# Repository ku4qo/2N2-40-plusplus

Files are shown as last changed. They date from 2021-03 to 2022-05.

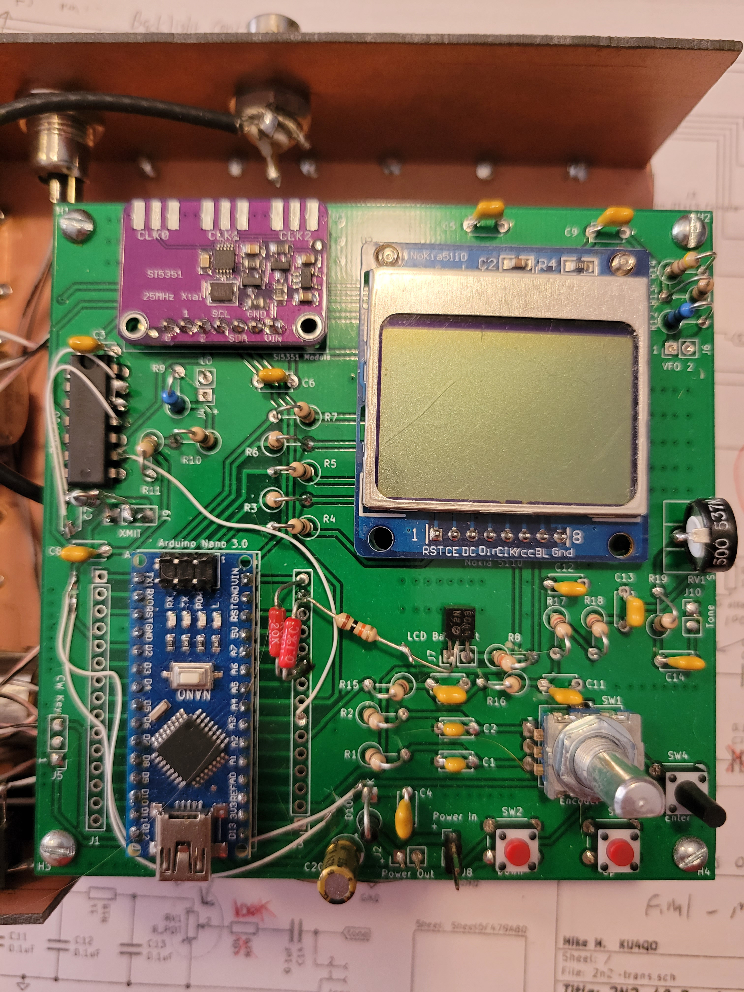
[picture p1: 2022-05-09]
digital board mods.jpg

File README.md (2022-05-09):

# 2N2-40-plusplus
This is very much an "alpha" level project. Proceed only if you want to get your hands dirty :)
Arduino software for the KU4QO version of K8IQY's 2n2-40 transceiver 
This is a work-in-progress. 
*VFO Program to run 2N2-40++ digital Transceiver - Press and hold enter on power up to start calibration
*swap pins XMIT_PWR and ENTER_BTN (D2 and D13) on digital board!
*si5351 clock 0 is vfo frequency, clock 1 is bfo frequency, clock 2 is transmit frequency; clock 0 is 
*temporarily used for calibrating the 25 MHz si5351 clock during the clock calibration routine.
*This version uses a Nokia 5110 LCD display.  Calibration routines use the enter button to advance.
*
Additional construction notes follow for these "alpha" version boards. See files "digital board mods" for additional details.

Attached is a photo of the digital board. There are a bunch of changes needed, so I figured a picture would help to follow along as well. Also attached are schematics of the boards as they were manufactured, along with lots of chicken-scratch writing about mods and values that were changed. You can see that the analog board is pretty much correct as-is, apart from a missing cap and a few value changes.

If you look at the two boards you'll see that the signals that travel between them have connectors in the exact same place. 

BFO
LO
Tone
Xmit
Power out digital/power in analog

The idea was to just have push-pin type connectors so that you could make the "sandwich" and easily pull it apart for changes or repairs. That didn't work out well for me so I used twisted-pair wires to connect between them. I don't notice any adverse results doing it that way. I'm sure it would work great with high-quality connectors, but the garbage ebay connectors I used were extremely noisy.

For the analog board, you need to add a 0.1uF cap across R11. Just tack solder it across the resistor or the pads. 

The winding information for all the inductors and transformers is printed on the schematic. The spots that have hand-written lengths in inches is me noting how much wire was needed to wind the coil. I used #28 wire. 

Transformer T6 is a little tricky since it has three windings. The sense of the windings is important. If you mix them up you'll make a very nice oscillator :)  The numbers start with odd, then end with even. So the first winding is 1 turn, starting at pin 1 and ending at pin 2. The next winding is 4 turns and starts at pin 3, goes in the same direction as the first winding, and ends at pin 4. Winding 3 starts at pin 5, goes in the same direction as the other two windings, and ends at pin 6. The pins are labeled on the pcb for clarity. 

Ground the IF crystal cases with a short wire to the spots labeled J10 through J13.

The audio output transformer has a P printed on one side. That is the primary (driven by the 2n2222 transistors). The unprinted side is the secondary (drives the speaker). 

Put a ferrite bead on the collector of Q4 before you solder it (for stability). 

The digital board requires a bunch of mods to get right. Here are my notes:

The schematic symbol for U4 says 74HC00, but it is important to use a 74ACT00. 

Be careful, there seem to be two different types of displays that have the Nokia display mounted on them. You can see the pins labeled in the photo attached. Make sure you buy and use a display that has the identical pinout. If you get one with the wrong pinout, it won't work as-is. 

On the 2 pin connector called "backlight", if you connect those pins the Nokia display backlight will turn on. Disconnect and it turns off. I was going to add computer control for this but ran out of output pins on the Arduino. So, on my board you'll see a transistor mounted in that spot. Ignore that and just add a jumper or a switch, or if you want the backlight on all the time, just short those two pins.

Add two resistors, 10k and 20k, as feedback to the Arduino for the supply voltage display. These don't have a position, so just solder them to the top of the board. You'll see that I used two red-colored resistors here. They are 0.1% resistors, but using regular 1% resistors is fine. If you don't have a 20k, use two 10k in series. 

There are two control lines that need to be swapped, which requires cutting traces and running mod wires. The Arudino nano has an LED that is attached to D13. If you use D13 as an input you have to remove that LED or the input doesn't work. Instead, I swapped what was connected to D2 with D13. You can see the two white mod wires that wrap around the bottom left corner of the arduino. The ends of those wires attach to the two trace cuts. One cut is by D100, and the other is by C8. 

You need to add a 10k resistor to ground from the XMIT_PWR line, which is now connect to Arudino pin D13 (after the mod above). This keeps the power off off of the finals during restart.

Before you install U4 (74ACT00), bend up pins 11, 12 and 13. Also, before you install it, cut the trace between pins 9 and 10. Do not load C7. Instead, use those pads as connection points for the mod wires. We're turning gate U4C from an inverter into a NAND gate, and using the spare U4D as an inverter. Pin 9 is then connected to Arduino pin A3. This allows us to gate the transmitter clock properly to keep the finals turned off during receive. 

For R19, use 100k instead of 10k. Use the 500 pot I sent as RV1. You'll have to be a little creative to solder in the pot since it doesn't match the pads. I bent the pins and used it vertically, and added a wire to the wiper connection down to the board. Also keep in mind that the pot is backwards, so fully clockwise is the lowest sidetone level, and it increases as you turn CCW. You won't need much since the audio amp is so sensitive, so start fully CW, then tweak carefully until you get the sidetone level you want. 

Both U4A and U4B drive attenuators before the signals go down to the mixers on the analog board. Use the resistor values in red for both of those attenuators. 

I'd suggest building the digital board first and getting it all working properly before you continue to the analog section. That way, you can check the outputs and make sure everything looks good before you build the analog board. You can test the display, swithces, Si5351 and keyer functions first before continuing. 

Just like all the other radios that use a class E amplifier for the finals (i.e. QCX), they are sensitive to being operated into an open or short circuit. When you first turn on the analog board, make sure you have a dummy load connected to the antenna, just in case something weird is happening and it tries to transmit. BS170 aren't expensive, but you don't want to smoke them if you can avoid it.

Notice that +12V power is first applied to the digital board, then routed down to the analog board. Each board has a schottky diode to protect it from reverse polarity. The two boards together draw about 140mA from my benchtop supply with no input signal. Yours should be close to that. If not, something is probably wrong.

Mine puts out a bit over 4 watts at 12VDC, and the amplifier is amazingly efficient. The entire radio only draws around 500mA when transmitting. 

Ok, I think that covers it. Take a look at the schematic and let me know if there are any parts that you don't have. If I have them I'll toss them in the box before I ship it on monday.

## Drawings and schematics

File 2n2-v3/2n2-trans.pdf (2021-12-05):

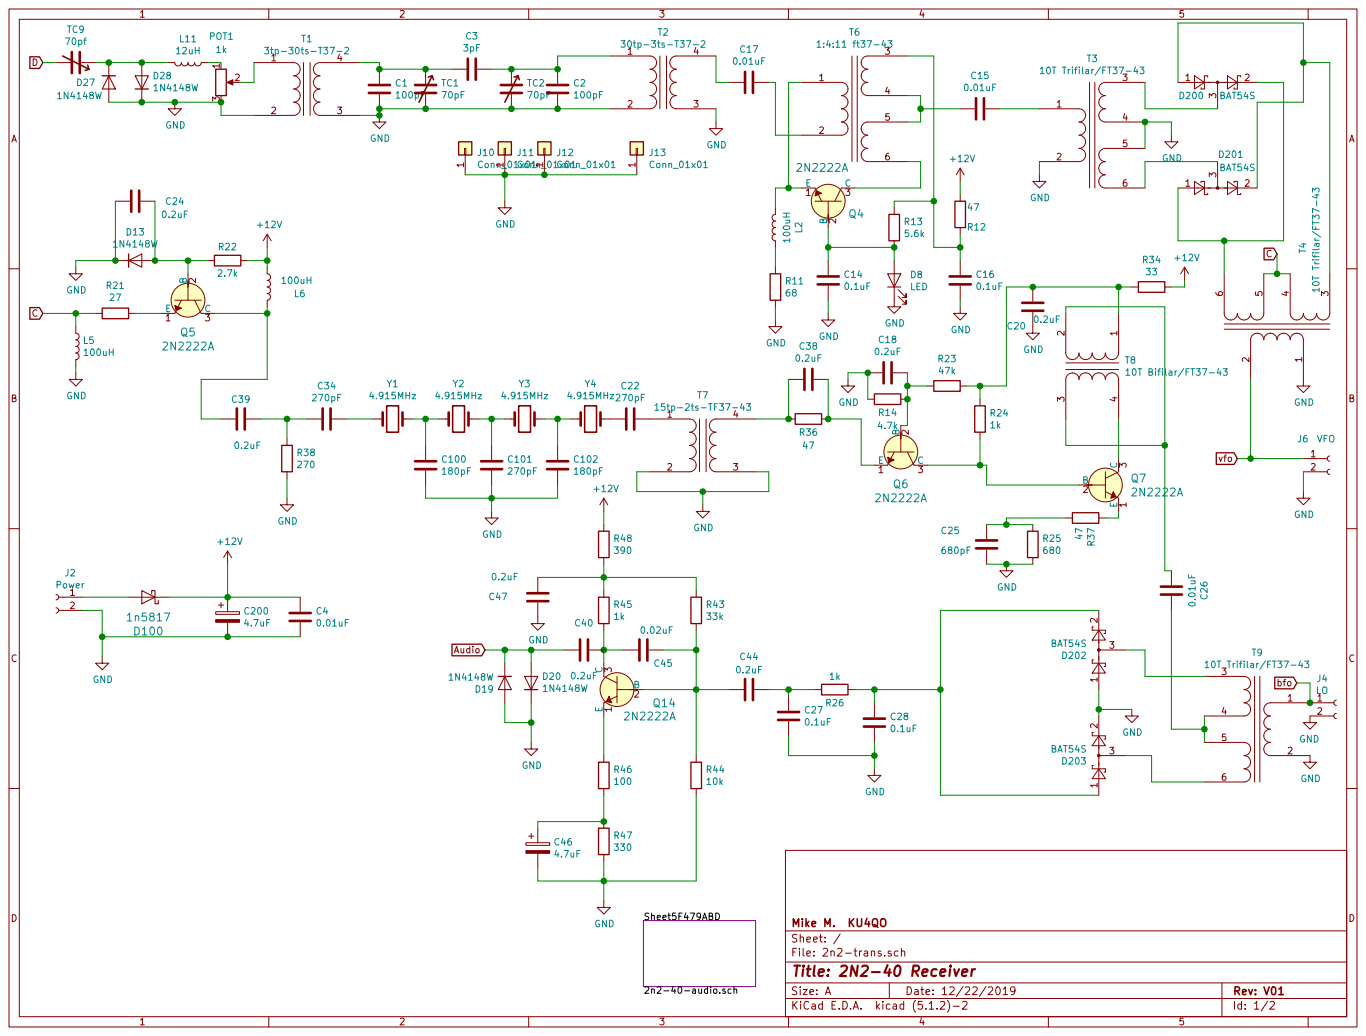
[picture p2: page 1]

Id: 1/2 Title: 2N2-40 Receiver File: 2n2-trans.sch Sheet: / Mike M. KU4QO

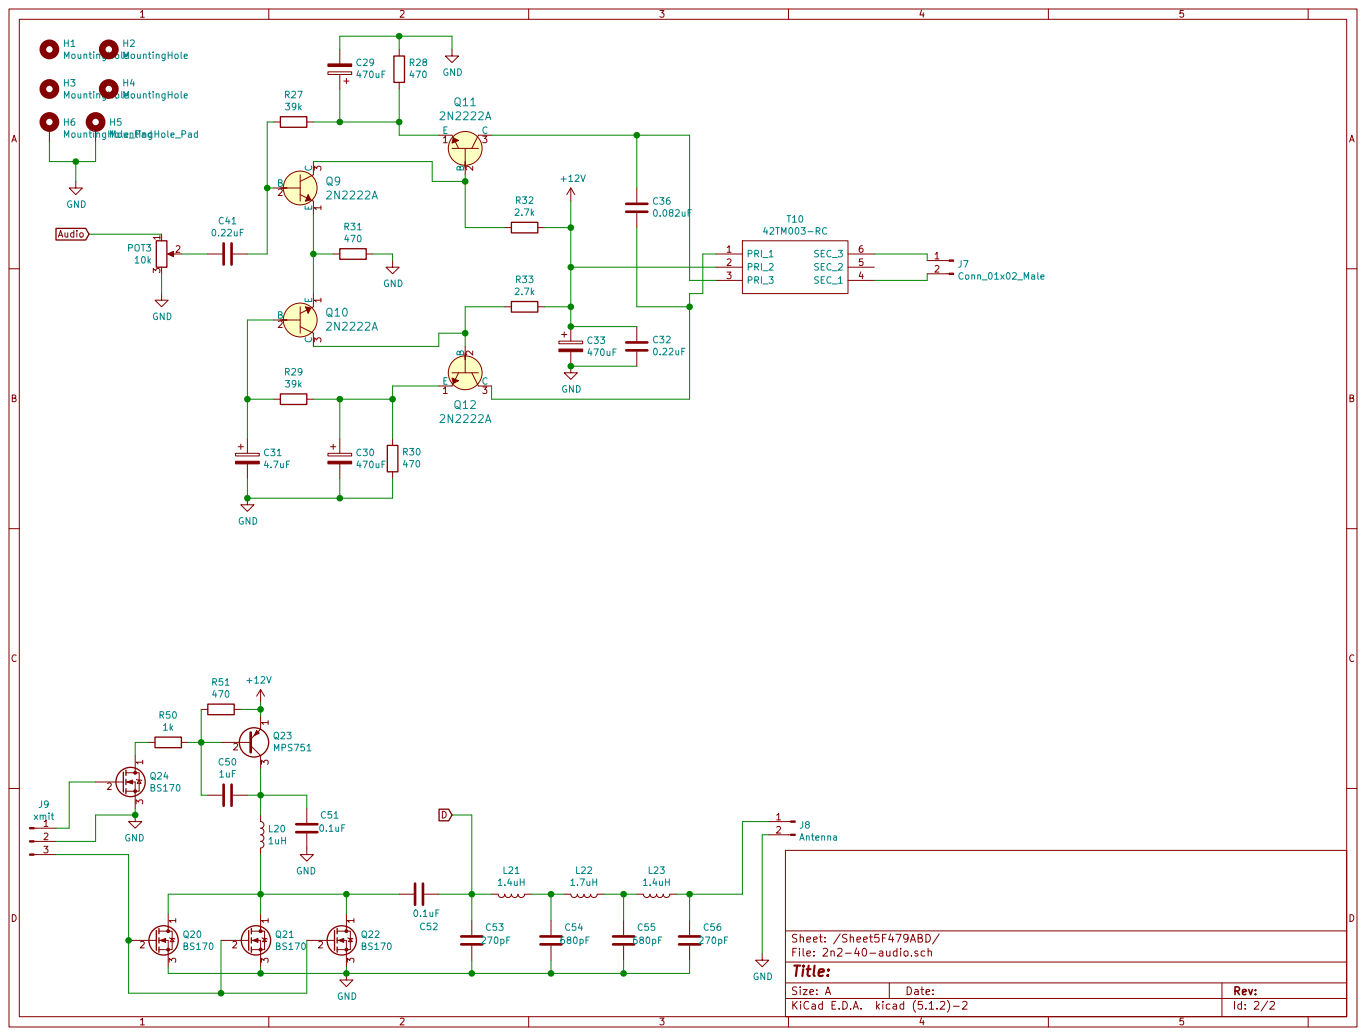
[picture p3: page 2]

Id: 2/2 Title: File: 2n2-40-audio.sch Sheet: /Sheet5F479ABD/

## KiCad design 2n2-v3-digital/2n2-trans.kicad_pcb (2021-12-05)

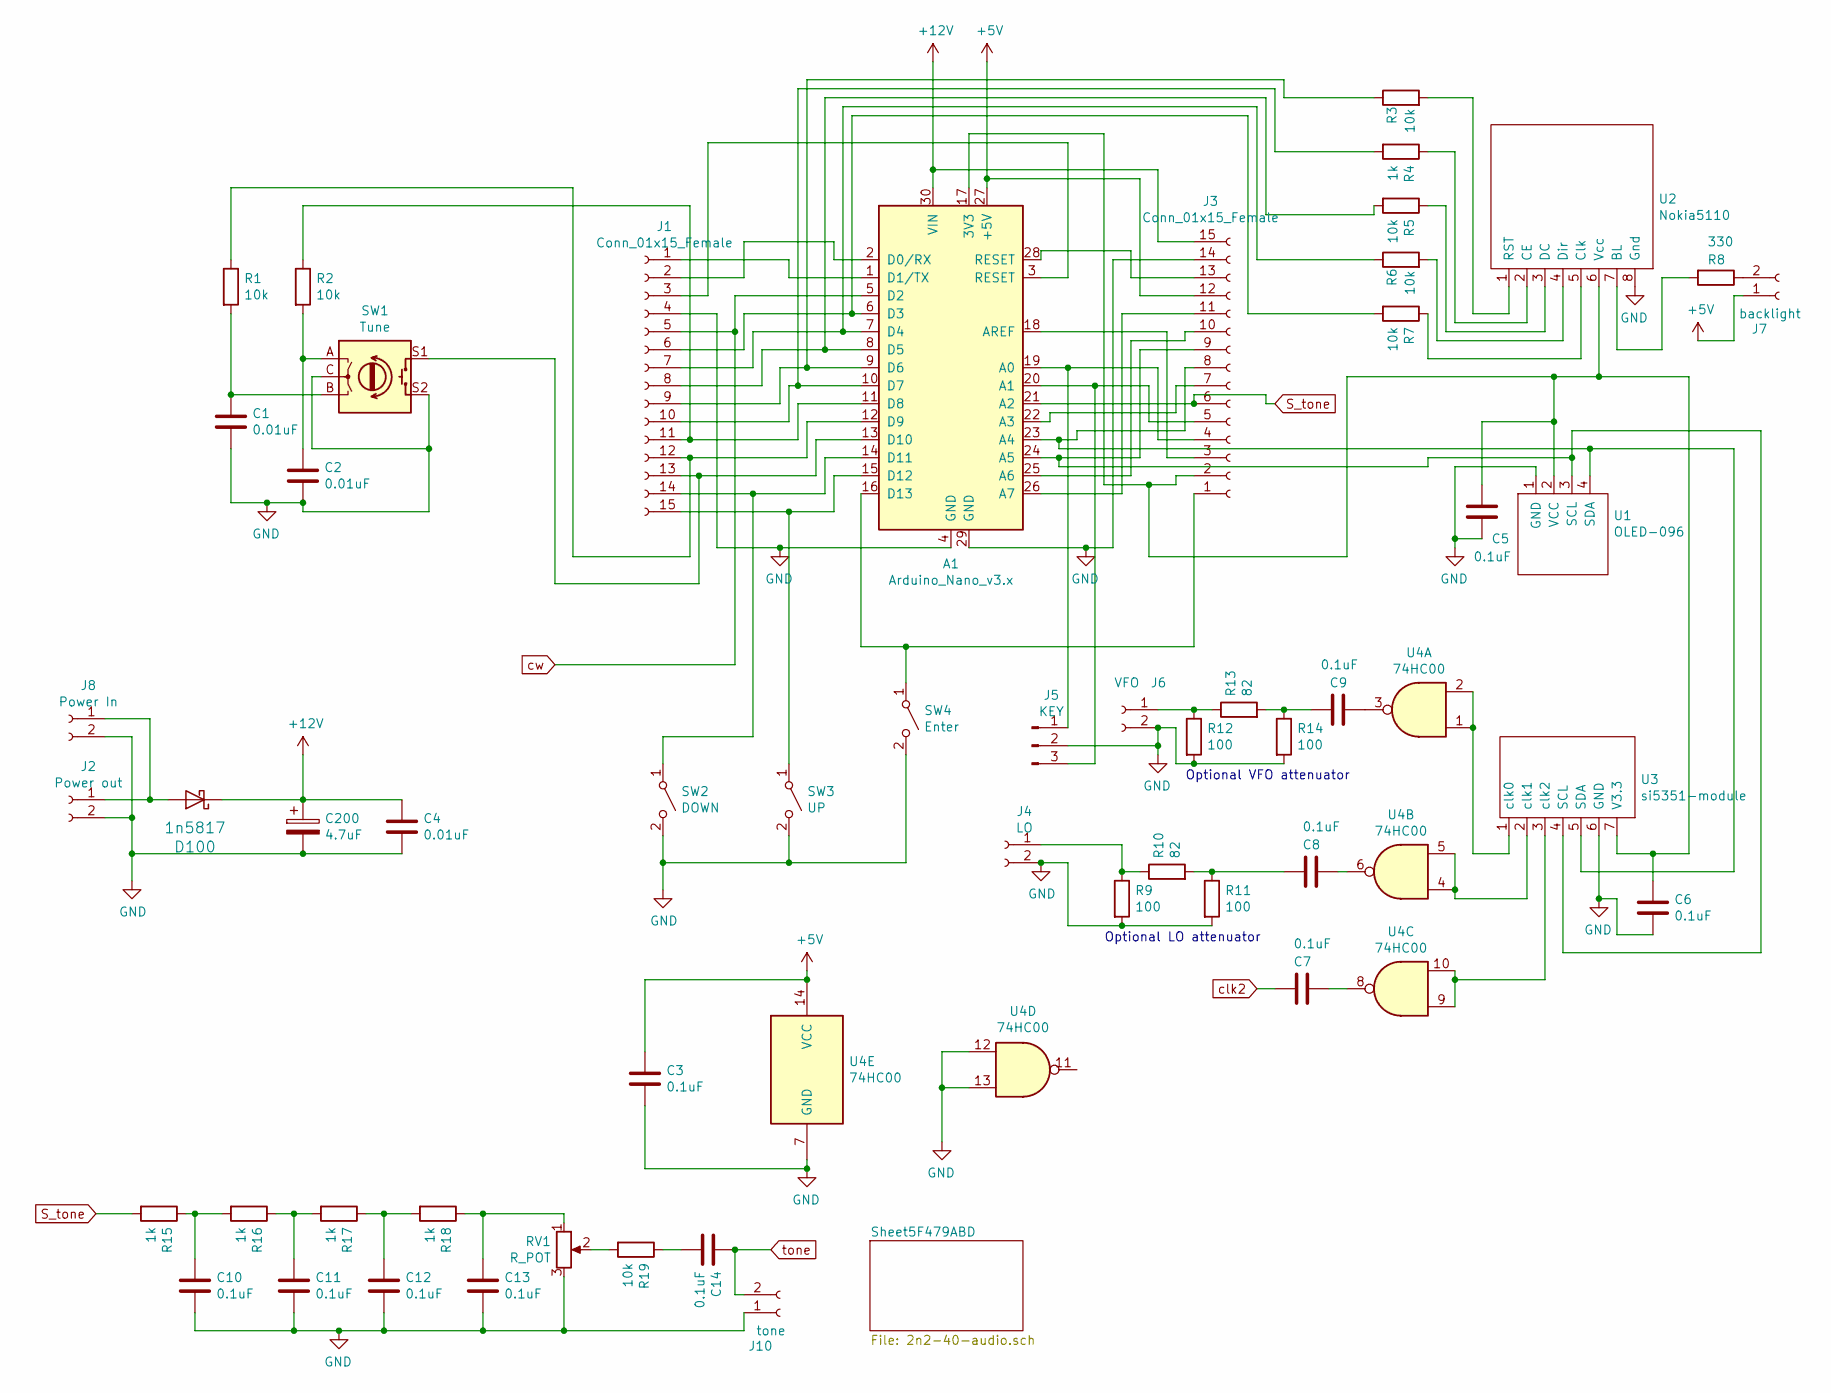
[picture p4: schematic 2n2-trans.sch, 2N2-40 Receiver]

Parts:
A1: Arduino_Nano_v3.x; Arduino_Nano
C1, C2, C4: 0.01uF; C_Disc_D4.7mm_W2.5mm_P5.00mm
C3, C5, C6, C7, C8, C9, C10, C11, C12, C13, C14: 0.1uF; C_Disc_D4.7mm_W2.5mm_P5.00mm
C200: 4.7uF; CP_Radial_D5.0mm_P2.00mm
D100: 1n5817; D_DO-41_SOD81_P3.81mm_Vertical_KathodeUp
J1, J3: Conn_01x15_Female; PinHeader_1x15_P2.54mm_Vertical
J2: Power out; PinHeader_1x02_P2.54mm_Vertical
J4: LO; PinHeader_1x02_P2.54mm_Vertical
J5: KEY; PinHeader_1x03_P2.54mm_Vertical
J6: VFO; PinHeader_1x02_P2.54mm_Vertical
J7: backlight; PinHeader_1x02_P2.54mm_Vertical
J8: Power In; PinHeader_1x02_P2.54mm_Vertical
J10: tone; PinHeader_1x02_P2.54mm_Vertical
R1, R2, R3, R5, R6, R7, R19: 10k; R_Axial_DIN0309_L9.0mm_D3.2mm_P5.08mm_Vertical
R4, R15, R16, R17, R18: 1k; R_Axial_DIN0309_L9.0mm_D3.2mm_P5.08mm_Vertical
R8: 330; R_Axial_DIN0309_L9.0mm_D3.2mm_P5.08mm_Vertical
R9, R11, R12, R14: 100; R_Axial_DIN0309_L9.0mm_D3.2mm_P5.08mm_Vertical
R10, R13: 82; R_Axial_DIN0309_L9.0mm_D3.2mm_P5.08mm_Vertical
RV1: R_POT; Potentiometer_Piher_PT-10-H01_Horizontal
SW1: Tune; RotaryEncoder_Alps_EC11E-Switch_Vertical_H20mm
SW2: DOWN; SW_PUSH_6mm_H5mm
SW3: UP; SW_PUSH_6mm_H5mm
SW4: Enter; SW_PUSH_6mm_H5mm
U1: OLED-096; oled096
U2: Nokia5110
U3: si5351-module
U4: 74HC00

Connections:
+5V: A1.27 (+5V), C3.1, J3.12, J7.1, U4.14 (VCC)
+12V: A1.30 (VIN), C4.1, C200.1, D100.1 (K), J3.15
GND: A1.4 (GND), A1.29 (GND), C1.2, C2.2, C3.2, C4.2, C5.2, C6.2, C10.2, C11.2, C12.2, C13.2, C200.2, J1.4, J2.2, J3.14, J4.2, J5.2, J6.2, J8.2, J10.1, R9.2, R11.2, R12.2, R14.2, RV1.3, SW1.C, SW1.S2, SW2.2 (B), SW3.2 (B), SW4.2 (B), U1.1 (GND), U2.8 (Gnd), U3.6 (GND), U4.7 (GND), U4.12, U4.13; also elsewhere on the board
unnamed: A1.1 (D1/TX), J1.1
unnamed: A1.2 (D0/RX), J1.2
unnamed: A1.3 (RESET), J1.3
unnamed: A1.6 (D3), J1.6, R7.2
unnamed: A1.7 (D4), J1.7, R6.1
unnamed: A1.8 (D5), J1.8, R5.2
unnamed: A1.9 (D6), J1.9, R3.1
unnamed: A1.10 (D7), J1.10, R4.2
unnamed: A1.11 (D8), J1.11, R2.1
unnamed: A1.12 (D9), J1.12, R1.1
unnamed: A1.13 (D10), J1.13, SW1.S1
unnamed: A1.14 (D11), J1.14, SW2.1 (A)
unnamed: A1.15 (D12), J1.15, SW3.1 (A)
unnamed: A1.16 (D13), J3.1, SW4.1 (A)
unnamed: A1.17 (3V3), C5.1, C6.1, J3.2, U1.2 (VCC), U2.6 (Vcc), U3.7 (V3.3)
unnamed: A1.18 (AREF), J3.3
unnamed: A1.19 (A0), J3.4, J5.1
unnamed: A1.20 (A1), J3.5, J5.3
unnamed: A1.22 (A3), J3.7
unnamed: A1.23 (A4), J3.8, U1.4 (SDA), U3.5 (SDA)
unnamed: A1.24 (A5), J3.9, U1.3 (SCL), U3.4 (SCL)
unnamed: A1.25 (A6), J3.10
unnamed: A1.26 (A7), J3.11
unnamed: A1.28 (RESET), J3.13
unnamed: C1.1, R1.2, SW1.B
unnamed: C2.1, R2.2, SW1.A
unnamed: C7.1, U4.8
unnamed: C8.1, U4.6
unnamed: C8.2, R10.2, R11.1
unnamed: C9.1, U4.3
unnamed: C9.2, R13.2, R14.1
unnamed: C10.1, R15.1, R16.2
unnamed: C11.1, R16.1, R17.2
unnamed: C12.1, R17.1, R18.2
unnamed: C13.1, R18.1, RV1.1
unnamed: C14.2, R19.1
unnamed: D100.2 (A), J2.1, J8.1
unnamed: J4.1, R9.1, R10.1
unnamed: J6.1, R12.1, R13.1
unnamed: J7.2, R8.1
unnamed: R3.2, U2.1 (RST)
unnamed: R4.1, U2.2 (CE)
unnamed: R5.1, U2.3 (DC)
unnamed: R6.2, U2.4 (Dir)
unnamed: R7.1, U2.5 (Clk)
unnamed: R8.2, U2.7 (BL)
unnamed: R19.2, RV1.2
unnamed: U3.1 (clk0), U4.1, U4.2
unnamed: U3.2 (clk1), U4.4, U4.5
unnamed: U3.3 (clk2), U4.9, U4.10
S_tone: A1.21 (A2), J3.6, R15.2
clk2: C7.2; also elsewhere on the board
cw: A1.5 (D2), J1.5; also elsewhere on the board
tone: C14.1, J10.2

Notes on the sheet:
Optional VFO attenuator
Optional LO attenuator

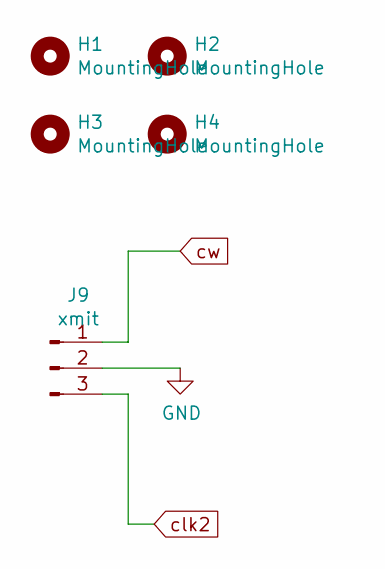
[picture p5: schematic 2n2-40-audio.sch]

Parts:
H1, H2, H3, H4: MountingHole; MountingHole_3.2mm_M3
J9: xmit; PinHeader_1x03_P2.54mm_Vertical

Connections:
GND: J9.2; also elsewhere on the board
clk2: J9.3; also elsewhere on the board
cw: J9.1; also elsewhere on the board

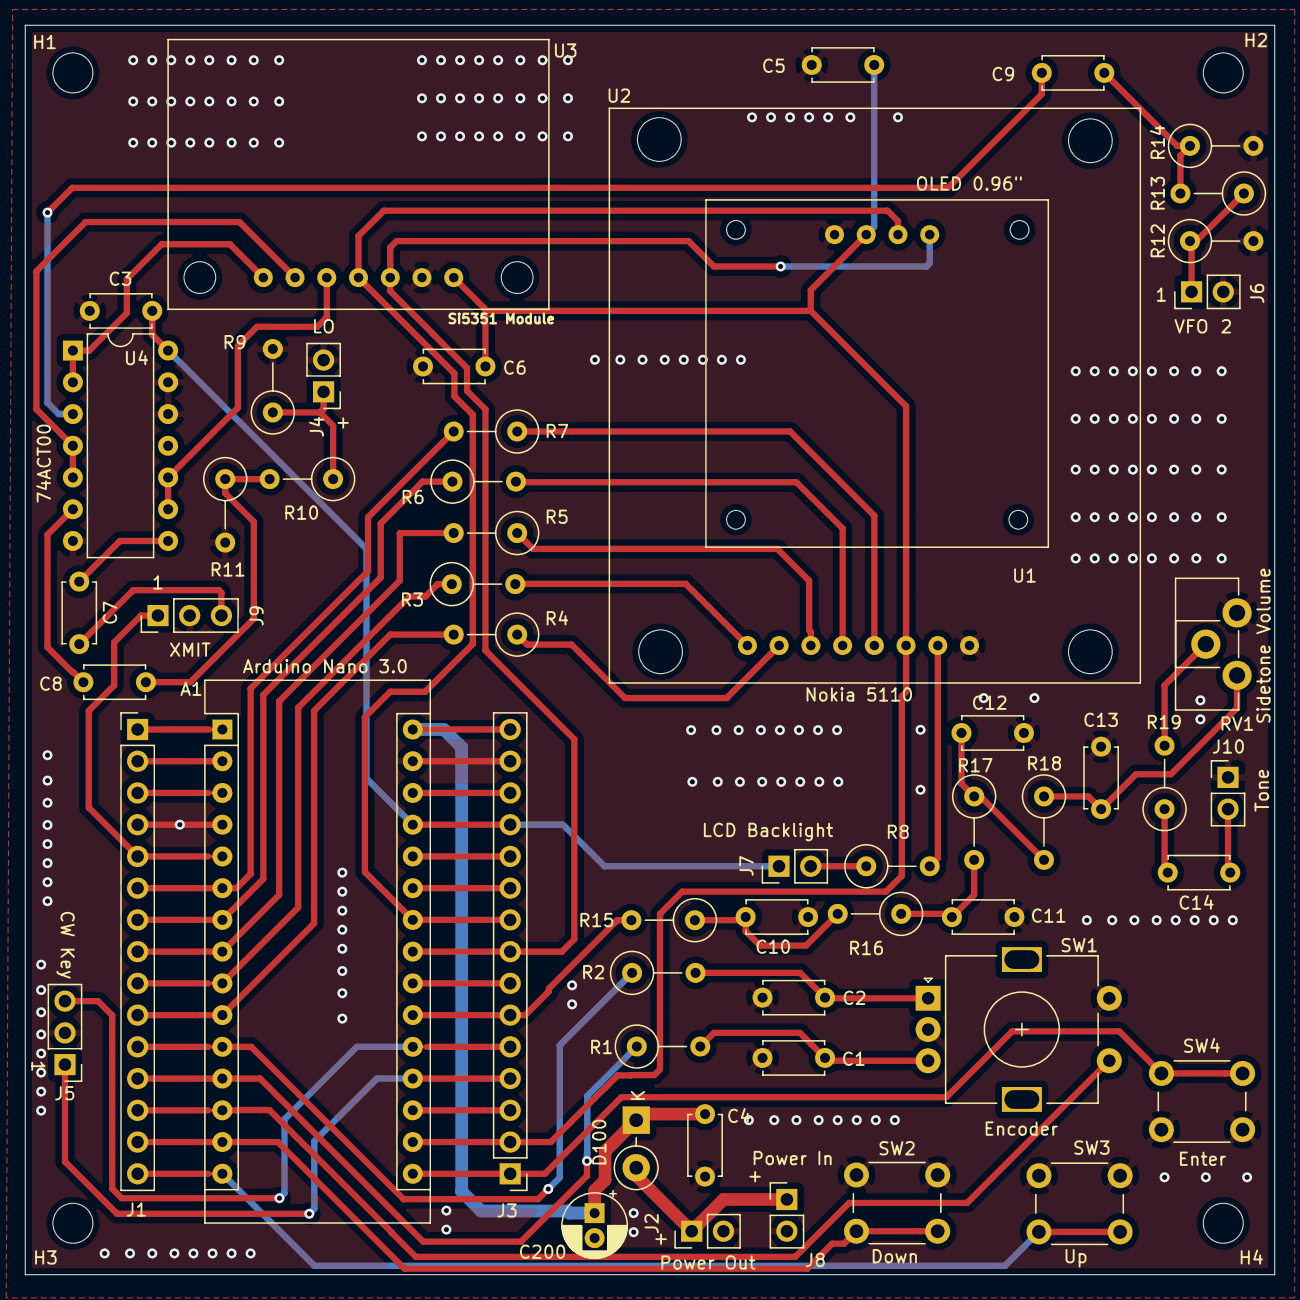
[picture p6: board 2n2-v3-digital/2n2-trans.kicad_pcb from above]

Board: 2 copper layers, 100.0 x 100.0 mm, 59 parts (0 on the bottom side), 57 nets.

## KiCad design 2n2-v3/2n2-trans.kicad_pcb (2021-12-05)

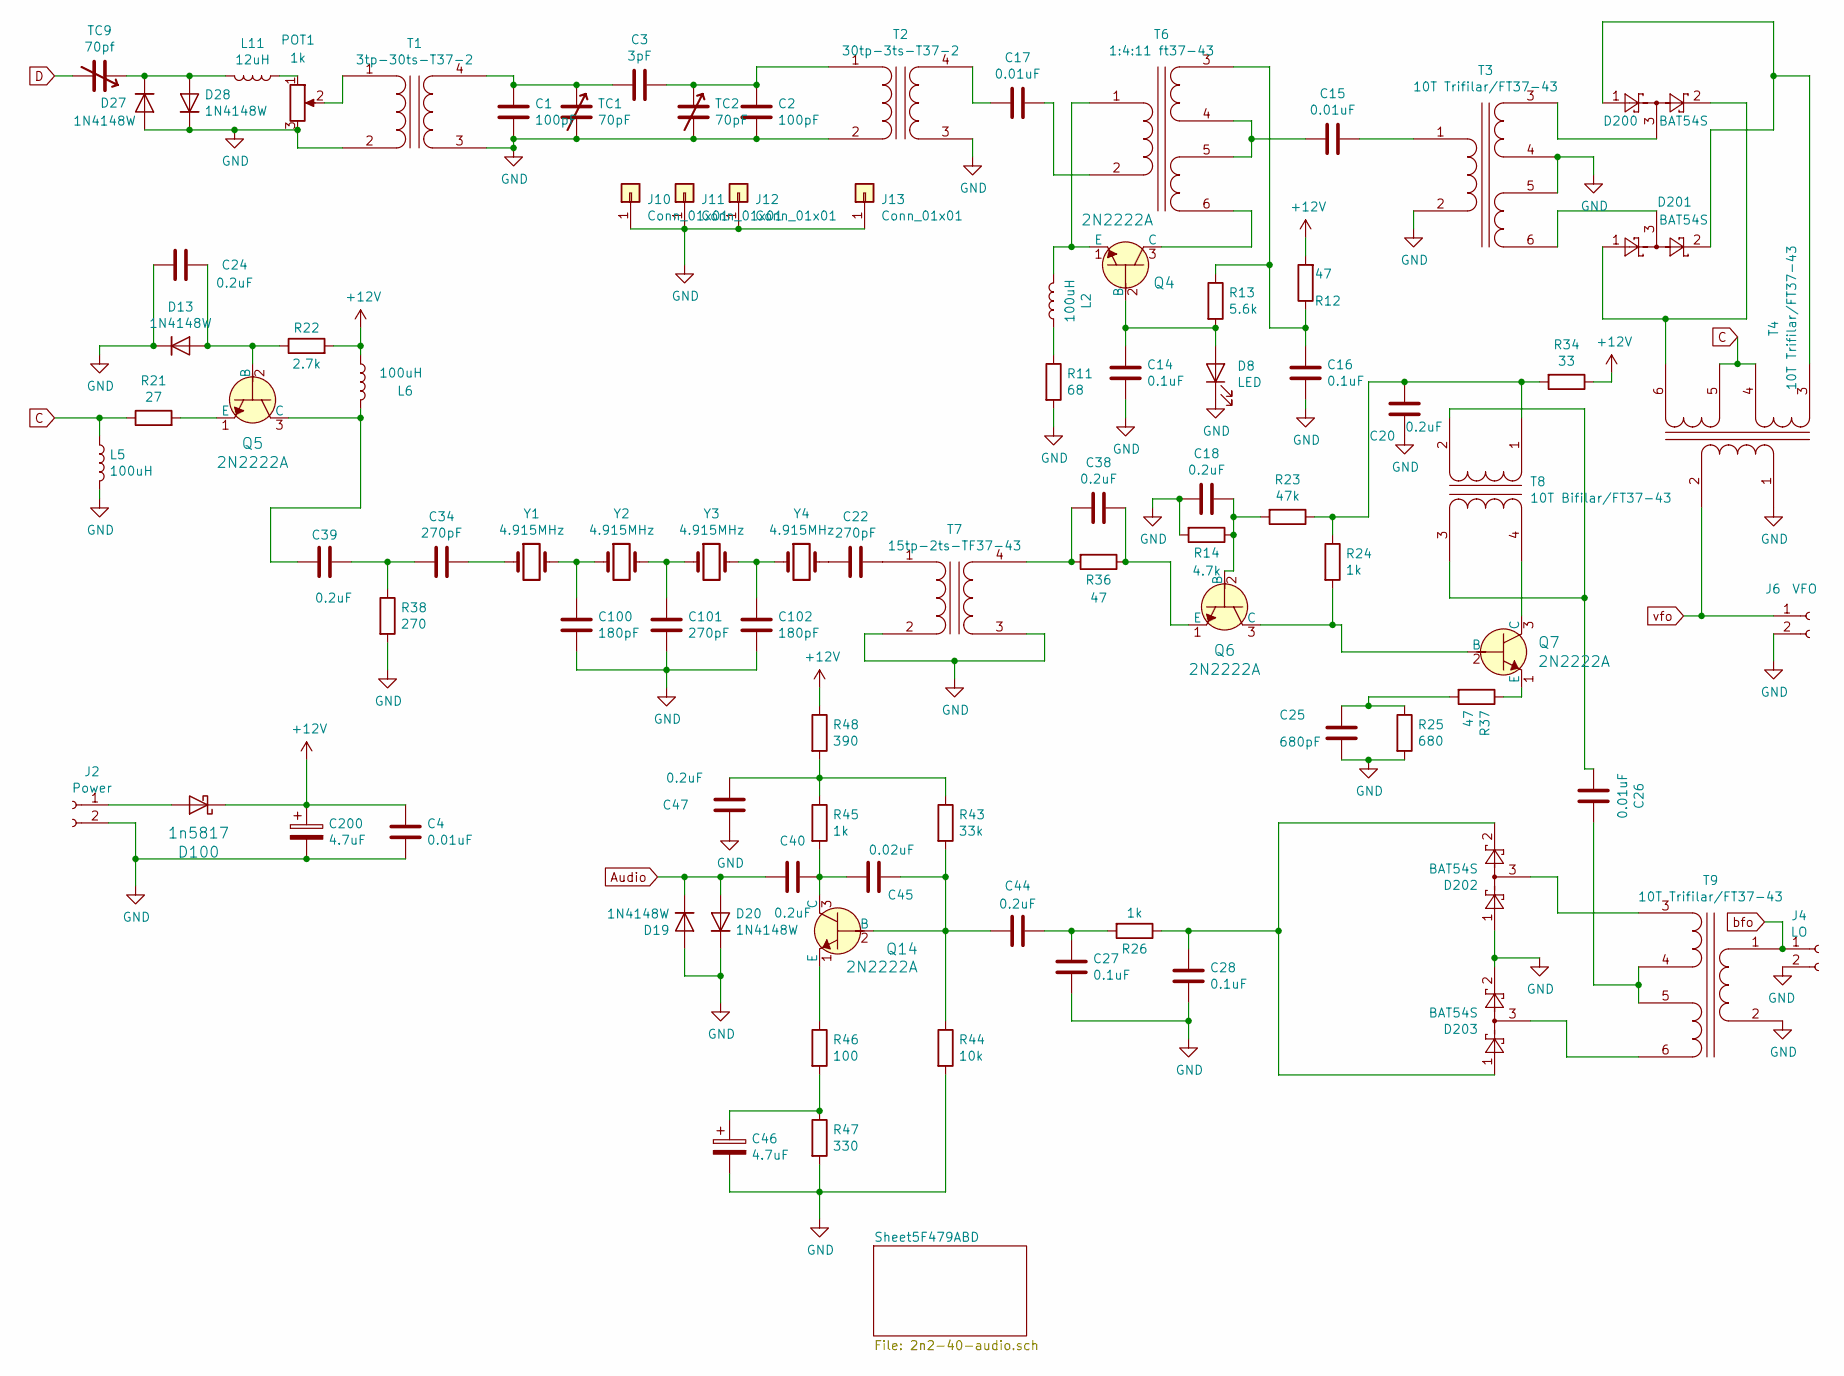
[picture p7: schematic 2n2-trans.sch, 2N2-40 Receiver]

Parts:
C1, C2: 100pF; C_Disc_D4.7mm_W2.5mm_P5.00mm
C3: 3pF; C_Disc_D4.7mm_W2.5mm_P5.00mm
C4: 0.01uF; C_Disc_D4.7mm_W2.5mm_P5.00mm
C14: 0.1uF; C_Disc_D4.7mm_W2.5mm_P5.00mm
C15, C17, C26: 0.01uF; C_Disc_D5.1mm_W3.2mm_P5.00mm
C16, C27, C28: 0.1uF; C_Disc_D5.1mm_W3.2mm_P5.00mm
C18, C20, C24, C38, C39, C40, C44, C47: 0.2uF; C_Disc_D5.1mm_W3.2mm_P5.00mm
C22, C34, C101: 270pF; C_Disc_D10.0mm_W2.5mm_P5.00mm
C25: 680pF; C_Disc_D5.1mm_W3.2mm_P5.00mm
C45: 0.02uF; C_Disc_D5.1mm_W3.2mm_P5.00mm
C46, C200: 4.7uF; CP_Radial_D5.0mm_P2.00mm
C100, C102: 180pF; C_Disc_D8.0mm_W2.5mm_P5.00mm
D8: LED; LED_D5.0mm
D13: 1N4148W; D_DO-35_SOD27_P2.54mm_Vertical_KathodeUp
D19, D20, D27, D28: 1N4148W; D_DO-41_SOD81_P3.81mm_Vertical_KathodeUp
D100: 1n5817; D_DO-41_SOD81_P3.81mm_Vertical_KathodeUp
D200, D201, D202, D203: BAT54S; SOT-23
J2: Power; PinHeader_1x02_P2.54mm_Vertical
J4: LO; PinHeader_1x02_P2.54mm_Vertical
J6: VFO; PinHeader_1x02_P2.54mm_Vertical
J10, J11, J12, J13: Conn_01x01; PinHeader_1x01_P1.27mm_Vertical
L2, L5, L6: 100uH; L_Axial_L7.0mm_D3.3mm_P5.08mm_Vertical_Fastron_MICC
L11: 12uH; L_Axial_L7.0mm_D3.3mm_P5.08mm_Vertical_Fastron_MICC
POT1: 1k; PinHeader_1x03_P2.54mm_Vertical
Q4, Q5, Q6, Q7, Q14: 2N2222A; TO-92_Inline; MPN 2N2222A; Digi-Key_PN 2N2222ACS-ND
R11: 68; R_Axial_DIN0309_L9.0mm_D3.2mm_P5.08mm_Vertical
R12, R36, R37: 47; R_Axial_DIN0309_L9.0mm_D3.2mm_P5.08mm_Vertical
R13: 5.6k; R_Axial_DIN0309_L9.0mm_D3.2mm_P5.08mm_Vertical
R14: 4.7k; R_Axial_DIN0309_L9.0mm_D3.2mm_P5.08mm_Vertical
R21: 27; R_Axial_DIN0309_L9.0mm_D3.2mm_P5.08mm_Vertical
R22: 2.7k; R_Axial_DIN0309_L9.0mm_D3.2mm_P5.08mm_Vertical
R23: 47k; R_Axial_DIN0309_L9.0mm_D3.2mm_P5.08mm_Vertical
R24, R26, R45: 1k; R_Axial_DIN0309_L9.0mm_D3.2mm_P5.08mm_Vertical
R25: 680; R_Axial_DIN0309_L9.0mm_D3.2mm_P5.08mm_Vertical
R34: 33; R_Axial_DIN0309_L9.0mm_D3.2mm_P5.08mm_Vertical
R38: 270; R_Axial_DIN0309_L9.0mm_D3.2mm_P5.08mm_Vertical
R43: 33k; R_Axial_DIN0309_L9.0mm_D3.2mm_P5.08mm_Vertical
R44: 10k; R_Axial_DIN0309_L9.0mm_D3.2mm_P5.08mm_Vertical
R46: 100; R_Axial_DIN0309_L9.0mm_D3.2mm_P5.08mm_Vertical
R47: 330; R_Axial_DIN0309_L9.0mm_D3.2mm_P5.08mm_Vertical
R48: 390; R_Axial_DIN0309_L9.0mm_D3.2mm_P5.08mm_Vertical
T1: 3tp-30ts-T37-2; ToroidTrans
T2: 30tp-3ts-T37-2; ToroidTrans
T3, T4, T9: 10T Trifilar/FT37-43; ToroidTri
T6: 1:4:11 ft37-43; ToroidTri
T7: 15tp-2ts-TF37-43; ToroidTrans
T8: 10T Bifilar/FT37-43; ToroidTrans
TC1, TC2: 70pF; tcap
TC9: 70pf; tcap
Y1, Y2, Y3, Y4: 4.915MHz; Crystal_HC49-U_Vertical

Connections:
+12V: C4.1, C200.1, D100.1 (K), L6.1, R12.2, R22.2, R34.1, R48.1; also elsewhere on the board
Audio: C40.1, D19.1 (K), D20.2 (A); also elsewhere on the board
C: L5.1, R21.1, T4.4 (SB), T4.5 (SC)
D: TC9.2; also elsewhere on the board
GND: C1.2, C2.2, C4.2, C14.2, C16.2, C18.2, C20.1, C24.2, C25.1, C27.2, C28.2, C46.2, C47.1, C100.2, C101.2, C102.2, C200.2, D8.1 (K), D13.1 (K), D19.2 (A), D20.1 (K), D27.2 (A), D28.1 (K), D202.1, D203.2, J2.2, J4.2, J6.2, J10.1, J11.1, J12.1, J13.1, L5.2, POT1.3, R11.2, R14.2, R25.2, R38.2, R44.2, R47.2, T1.2 (AB), T1.3 (SA), T2.2 (AB), T2.3 (SA), T3.2 (AB), T3.4 (SB), T3.5 (SC), T4.1 (AA), T7.2 (AB), T7.3 (SA), T9.2 (AB), TC1.2, TC2.2; also elsewhere on the board
unnamed: C1.1, C3.2, T1.4 (SB), TC1.1
unnamed: C2.1, C3.1, T2.1 (AA), TC2.1
unnamed: C14.1, D8.2 (A), Q4.2 (B), R13.2
unnamed: C15.1, T3.1 (AA)
unnamed: C15.2, T6.4 (SB), T6.5 (SC)
unnamed: C16.1, R12.1, R13.1, T6.3 (SA)
unnamed: C17.1, T6.2 (AB)
unnamed: C17.2, T2.4 (SB)
unnamed: C18.1, Q6.2 (B), R14.1, R23.2
unnamed: C20.2, R23.1, R24.1, R34.2, T8.1 (AA)
unnamed: C22.1, T7.1 (AA)
unnamed: C22.2, Y4.2
unnamed: C24.1, D13.2 (A), Q5.2 (B), R22.1
unnamed: C25.2, R25.1, R37.2
unnamed: C26.1, T9.4 (SB), T9.5 (SC)
unnamed: C26.2, T8.2 (AB), T8.3 (SA)
unnamed: C27.1, C44.1, R26.2
unnamed: C28.1, D202.2, D203.1, R26.1
unnamed: C34.1, Y1.1
unnamed: C34.2, C39.1, R38.1
unnamed: C38.1, Q6.1 (E), R36.1
unnamed: C38.2, R36.2, T7.4 (SB)
unnamed: C39.2, L6.2, Q5.3 (C)
unnamed: C40.2, C45.2, Q14.3 (C), R45.2
unnamed: C44.2, C45.1, Q14.2 (B), R43.2, R44.1
unnamed: C46.1, R46.2, R47.1
unnamed: C47.2, R43.1, R45.1, R48.2
unnamed: C100.1, Y1.2, Y2.1
unnamed: C101.1, Y2.2, Y3.1
unnamed: C102.1, Y3.2, Y4.1
unnamed: D27.1 (K), D28.2 (A), L11.2, TC9.1
unnamed: D100.2 (A), J2.1
unnamed: D200.1, D201.2, T4.3 (SA)
unnamed: D200.2, D201.1, T4.6 (SD)
unnamed: D200.3, T3.3 (SA)
unnamed: D201.3, T3.6 (SD)
unnamed: D202.3, T9.3 (SA)
unnamed: D203.3, T9.6 (SD)
unnamed: L2.1, R11.1
unnamed: L2.2, Q4.1 (E), T6.1 (AA)
unnamed: L11.1, POT1.1
unnamed: POT1.2, T1.1 (AA)
unnamed: Q4.3 (C), T6.6 (SD)
unnamed: Q5.1 (E), R21.2
unnamed: Q6.3 (C), Q7.2 (B), R24.2
unnamed: Q7.1 (E), R37.1
unnamed: Q7.3 (C), T8.4 (SB)
unnamed: Q14.1 (E), R46.1
bfo: J4.1, T9.1 (AA)
vfo: J6.1, T4.2 (AB)

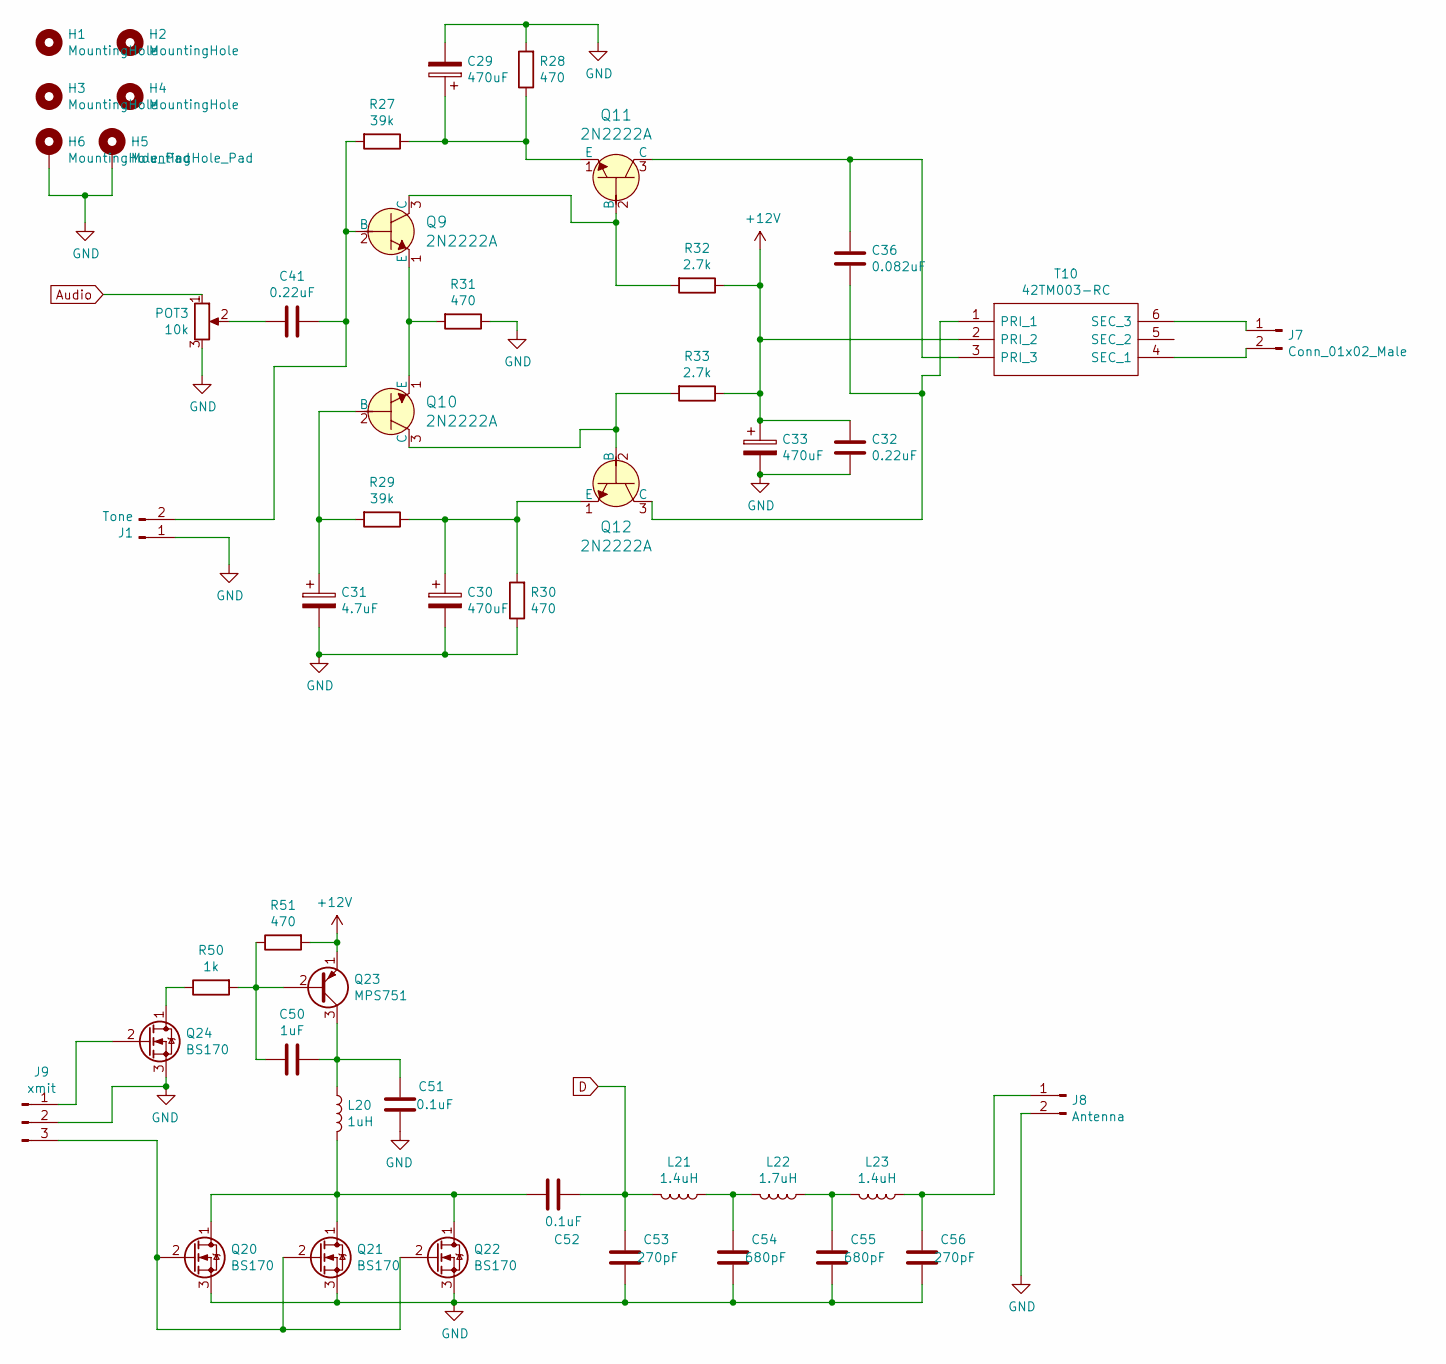
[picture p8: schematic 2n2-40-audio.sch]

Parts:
C29, C30, C33: 470uF; CP_Radial_D8.0mm_P3.50mm
C31: 4.7uF; CP_Radial_D5.0mm_P2.00mm
C32, C41: 0.22uF; C_Disc_D5.1mm_W3.2mm_P5.00mm
C36: 0.082uF; C_Disc_D5.1mm_W3.2mm_P5.00mm
C50: 1uF; C_Disc_D10.0mm_W2.5mm_P5.00mm
C51, C52: 0.1uF; C_Disc_D10.0mm_W2.5mm_P5.00mm
C53, C56: 270pF; C_Disc_D10.0mm_W2.5mm_P5.00mm
C54, C55: 680pF; C_Disc_D10.0mm_W2.5mm_P5.00mm
H1, H2, H3, H4: MountingHole; MountingHole_3.2mm_M3
H5, H6: MountingHole_Pad; MountingHole_2.2mm_M2_Pad_Via
J1: Tone; PinHeader_1x02_P2.54mm_Vertical
J7: Conn_01x02_Male; PinHeader_1x02_P2.54mm_Vertical
J8: Antenna; PinHeader_1x02_P2.54mm_Vertical
J9: xmit; PinHeader_1x03_P2.54mm_Vertical
L20: 1uH; L_Axial_L5.3mm_D2.2mm_P7.62mm_Horizontal_Vishay_IM-1
L21, L23: 1.4uH; L_Axial_L5.3mm_D2.2mm_P7.62mm_Horizontal_Vishay_IM-1
L22: 1.7uH; L_Axial_L5.3mm_D2.2mm_P7.62mm_Horizontal_Vishay_IM-1
POT3: 10k; PinHeader_1x03_P2.54mm_Vertical
Q9, Q10, Q11, Q12: 2N2222A; TO-92_Inline; MPN 2N2222A; Digi-Key_PN 2N2222ACS-ND
Q20, Q21, Q22, Q24: BS170; TO-92_Inline
Q23: MPS751; TO-92_Inline
R27, R29: 39k; R_Axial_DIN0309_L9.0mm_D3.2mm_P5.08mm_Vertical
R28, R30, R31, R51: 470; R_Axial_DIN0309_L9.0mm_D3.2mm_P5.08mm_Vertical
R32, R33: 2.7k; R_Axial_DIN0309_L9.0mm_D3.2mm_P5.08mm_Vertical
R50: 1k; R_Axial_DIN0309_L9.0mm_D3.2mm_P5.08mm_Vertical
T10: 42TM003-RC; DIPS1270W61P356L2200H1699Q6N; Mouser Part Number 42TM003-RC

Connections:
+12V: C32.2, C33.1, Q23.1 (E), R32.1, R33.1, R51.2, T10.2 (PRI_2); also elsewhere on the board
Audio: POT3.1; also elsewhere on the board
D: C52.1, C53.1, L21.2; also elsewhere on the board
GND: C29.2, C30.2, C31.2, C32.1, C33.2, C51.2, C53.2, C54.2, C55.2, C56.2, H5.1, H6.1, J1.1, J8.2, J9.2, POT3.3, Q20.3 (S), Q21.3 (S), Q22.3 (S), Q24.3 (S), R28.2, R30.1, R31.1; also elsewhere on the board
unnamed: C29.1, Q11.1 (E), R27.1, R28.1
unnamed: C30.1, Q12.1 (E), R29.1, R30.2
unnamed: C31.1, Q10.2 (B), R29.2
unnamed: C36.1, Q12.3 (C), T10.1 (PRI_1)
unnamed: C36.2, Q11.3 (C), T10.3 (PRI_3)
unnamed: C41.1, J1.2, Q9.2 (B), R27.2
unnamed: C41.2, POT3.2
unnamed: C50.1, Q23.2 (B), R50.2, R51.1
unnamed: C50.2, C51.1, L20.1, Q23.3 (C)
unnamed: C52.2, L20.2, Q20.1 (D), Q21.1 (D), Q22.1 (D)
unnamed: C54.1, L21.1, L22.2
unnamed: C55.1, L22.1, L23.2
unnamed: C56.1, J8.1, L23.1
unnamed: J7.1, T10.6 (SEC_3)
unnamed: J7.2, T10.4 (SEC_1)
unnamed: J9.1, Q24.2 (G)
unnamed: J9.3, Q20.2 (G), Q21.2 (G), Q22.2 (G)
unnamed: Q9.1 (E), Q10.1 (E), R31.2
unnamed: Q10.3 (C), Q12.2 (B), R33.2
unnamed: Q9.3 (C), Q11.2 (B), R32.2
unnamed: Q24.1 (D), R50.1

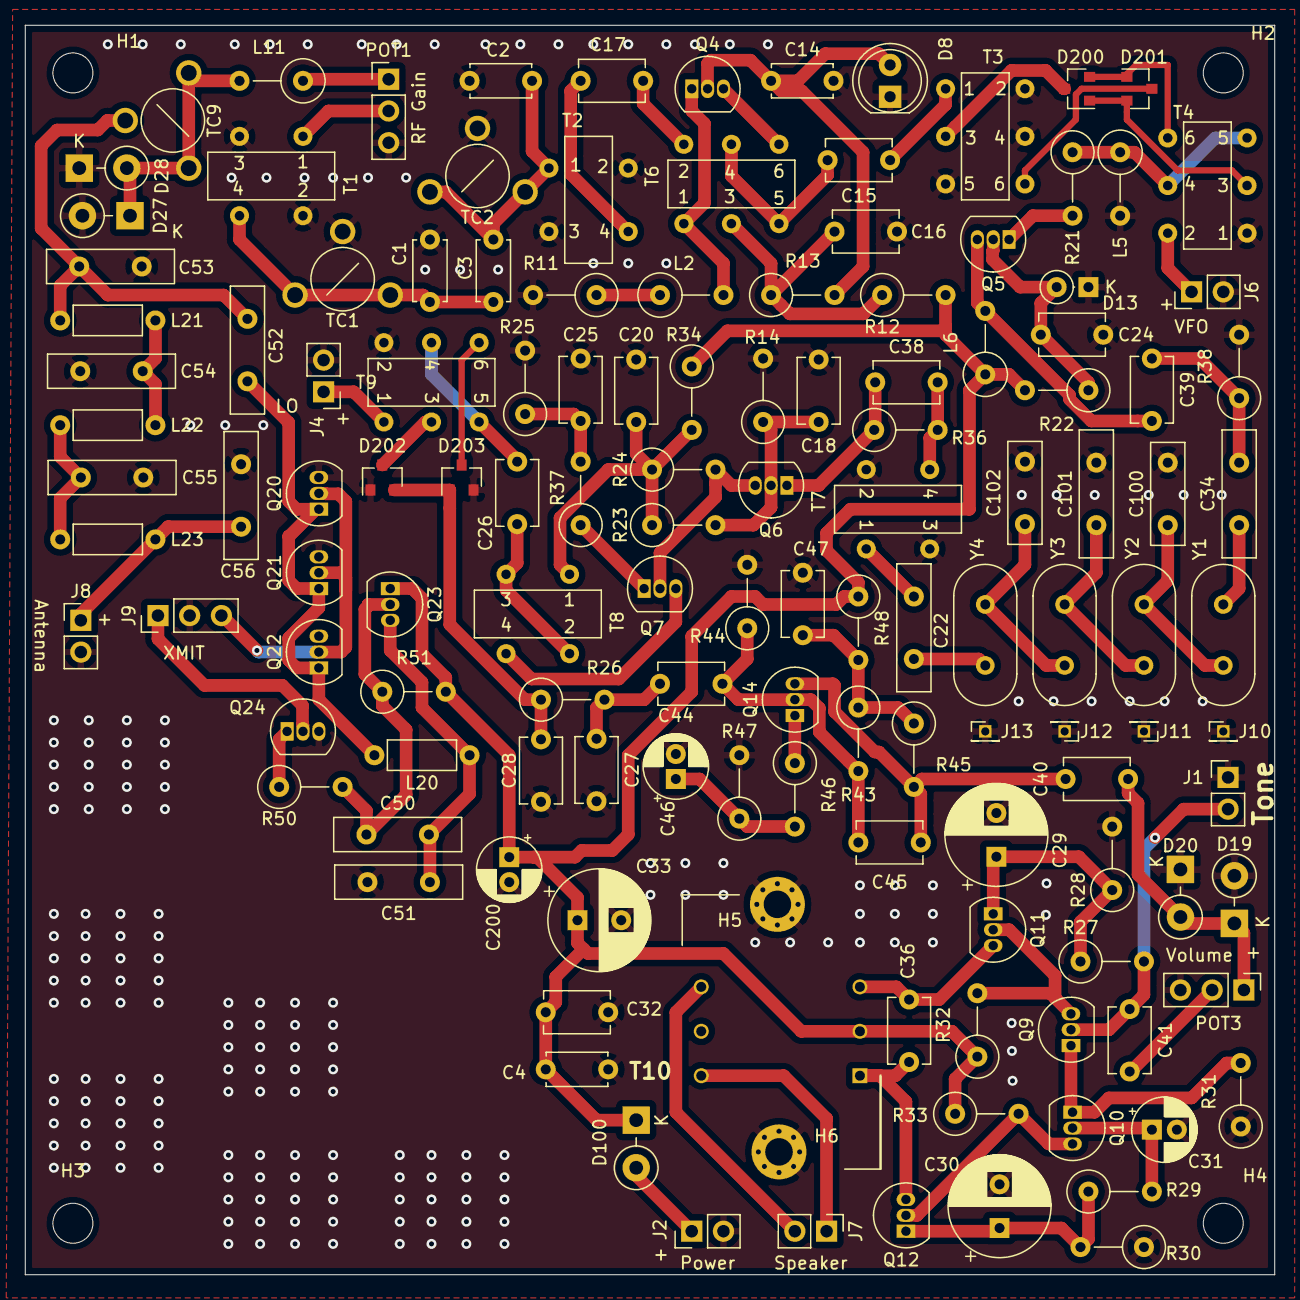
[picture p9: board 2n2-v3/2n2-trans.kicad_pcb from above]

Board: 2 copper layers, 100.0 x 100.0 mm, 139 parts (0 on the bottom side), 76 nets.

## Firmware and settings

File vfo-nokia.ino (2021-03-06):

/*VFO Program to run 2N2-40++ Transceiver - Press and hold enter on power up to start calibration
*swap pins XMIT_PWR and ENTER_BTN (D2 and D13)
*si5351 clock 0 is vfo frequency, clock 1 is bfo frequency, clock 2 is transmit frequency; clock 0 is 
*temporarily used for calibrating the 25 MHz si5351 clock during the clock calibration routine.
*This version uses a Nokia 5110 LCD display.  Calibration routines use the enter button to advance.
 */

#define NOKIA 0
#include <si5351mcu.h>
#include <Wire.h>
#include <Rotary.h>
#include <EEPROM.h>
#ifdef NOKIA
  #include <PCD8544.h>
#endif
#define ENTER_BTN     2
#define ENCODER_A     8       // Encoder pin A 
#define ENCODER_B     9       // Encoder pin B 
#define ENCODER_BTN   10      // Encoder pushbutton
#define DOWN_BTN      11
#define UP_BTN        12
#define XMIT_PWR      13

#define DIT_KEY       A0      //CW connector pin 1
#define DAH_KEY       A1      //CW connector pin 3
#define S_TONE        A2      //sidetone output square wave
//#define BACKLIGHT     A3
#define XMIT_EN       A3
#define VOLTS         A6

#define EE_SAVED_FQ     0   // spot to save tuned frequency 
#define EE_SAVED_CAL    4   // si5351 calibration value
#define EE_SAVED_BFO    8   // calibrated BFO frequency
#define EE_KEYER_SPEED  12  // spot to save keyer speed

//keyercontrol flags
#define     DIT_L      0x01     // Dit latch
#define     DAH_L      0x02     // Dah latch
#define     DIT_PROC   0x04     // Dit is being processed
#define     PDLSWAP    0x08     // 0 for normal, 1 for swap
#define     IAMBICB    0x10     // 0 for Iambic A, 1 for Iambic B

#define if_guess 4913925; //estimate of IF frequency center freq. - used for uncalibrated device
long if_freq=4913925; //initial if frequency, used for calculations

long cw_offset=600;
long fq=7030000; //initial startup frequency
long vfo;
long bfo;
long cal_ofst=0;
char LCDstr[14];   //Holds the displayed frequency
const float vpb=0.0048828;   //volts per bit of ADC 
float vbatt;

int step_array[6]={1, 10, 100, 500, 1000, 10000}; // step values in Hz
int step_index=3;                                 // initial step value 100Hz

unsigned long       ditTime;                    // No. milliseconds per dit
unsigned char       keyerControl;
unsigned char       keyerState;
enum KSTYPE {IDLE, CHK_DIT, CHK_DAH, KEYED_PREP, KEYED, INTER_ELEMENT };
byte wpm;

//Declare hardware being used
Si5351mcu Si;
Rotary r = Rotary(ENCODER_A, ENCODER_B);
PCD8544 lcd;

void set_frequency(short dir)
{
  fq=fq+(dir * step_array[step_index]);   //change freq by step size
  vfo=fq-if_freq;                         //calculate vfo frequency
  Si.setFreq(0, vfo);                     //call lib to set frequency
}

void calib(void)              //System calibration function, Si5351 clock and BFO
{
  long cal_fq = 10000000; 
  long cal_orig = cal_ofst;   //save existing cal value
  lcd.clear();
  lcd.setCursor(0,0);         //set cursor to column 0, row 1
  lcd.print("ADJ. CLK0 TO");
  lcd.setCursor(0,1);         //set cursor to row 2
  lcd.print("10MHz");  
  lcd.setCursor(0,2);         //set cursor to row 2
  lcd.print("CHG WITH ENC");  
  lcd.setCursor(0,3);         //set cursor to row 3
  lcd.print("ENTER TO CONT.");
  wait_key();                   //wait for "Enter" key press, then continue
  lcd.clear();
  disp_freq(cal_fq);
  disp_step(cal_fq);
  Si.disable(1);  //turn off bfo - not needed
  Si.setFreq(0, cal_fq);
  while ( digitalRead(ENTER_BTN) ) {      //enter_btn is "true" until pushed
 
    char result = r.process();
    if (result) {               //execute if encoder moved
      if (result == DIR_CW) {
        cal_fq = cal_fq + step_array[step_index];
        Si.setFreq(0, cal_fq);
        disp_freq(cal_fq);
      }
      else if (result == DIR_CCW) {
        cal_fq = cal_fq + (-1 * step_array[step_index]);
        Si.setFreq(0, cal_fq);
        disp_freq(cal_fq);
      }
    }
    check_step_change(cal_fq);    // check if step size buttons pressed
  }
 cal_ofst = 10000000 - cal_fq; //find difference from 10MHz reference
 cal_ofst *= 2.5;                //calculate 25MHz crystal offset value
 cal_ofst += cal_orig;           //factor back in original offset saved in eeprom
 disp_freq(cal_ofst);            //display ofset value
 delay(1000);
 wait_key();

 eeprom_write_dword((uint32_t *)EE_SAVED_CAL, cal_ofst); //save new cal in eeprom
 Si.correction(cal_ofst);       //set new calibration
 bfo=if_freq-cw_offset;         //calculate bfo frequency
 Si.setFreq(1, bfo);            //call lib to set bfo frequency
 Si.enable(1);                  //turn on bfo
 vfo=fq-if_freq;                    //calculate vfo frequency
 Si.setFreq(0, vfo);            //call lib to set vfo frequency 
 Si.enable(0);                  //turn on vfo 

//Si5351 calibration complete; Begin BFO calibration
 
  lcd.setCursor(0,0);         //set cursor to column 0, row 1
  lcd.print("ADJ. IF FREQ.");
  lcd.setCursor(0,1);         //set cursor to row 2
  lcd.print("MATCH IF FIL.");  
  lcd.setCursor(0,2);         //set cursor to row 3
  lcd.print("CENTER @ 600Hz");
  lcd.setCursor(0,3);         //set cursor to row 4
  lcd.print("USB");
  lcd.setCursor(0,4);         //set cursor to row 4
  lcd.print("ENTER TO CONT.");
  wait_key();                 //wait for ENTER_BTN key press then continue
  lcd.clear();                // clear screen and display if freq and step pointer
  disp_freq(if_freq);
  disp_step(if_freq);

  while ( digitalRead(ENTER_BTN) ) {
    char result = r.process();
    if (result) { //execute if encoder moved
      if (result == DIR_CW) {
        if_freq += step_array[step_index];
        bfo = if_freq - cw_offset;
        Si.setFreq(1, bfo);
        disp_freq(if_freq);
      }
      else if (result == DIR_CCW) {
        if_freq += (-1 * step_array[step_index]);
        bfo = if_freq - cw_offset;
        Si.setFreq(1, bfo);
        disp_freq(if_freq);
      }
      }
    check_step_change(if_freq);
  }
  wait_key();
  eeprom_write_dword((uint32_t *)EE_SAVED_BFO, if_freq); //save new if frequency cal in eeprom
}

void wait_key(void)
{
  while ( digitalRead(ENTER_BTN) ) {}
  delay(100);
  while ( !digitalRead(ENTER_BTN) ) {}
  delay(100);
}

void disp_freq(long freq)
{
  long fq_m=freq / 1000000;   // parse frequency to display into chunks
  long rm = freq % 1000000;
  long fq_k=rm / 1000;
  long fq_h = rm % 1000;
  sprintf(LCDstr, "%.1ld,%.3ld.%.3ld kHz", fq_m, fq_k, fq_h );  //create string with proper formatting
  lcd.setCursor(0, 0);        // set the cursor to column 5, line 0
  lcd.clearLine();            // clear old data from display
  lcd.print(LCDstr);
}

void check_step_change(long fq2)
{
    if ( !digitalRead(DOWN_BTN) )
    {
      step_index+=1;
      if (step_index > 5 ) 
      {
       step_index = 0;
      }
      disp_step(fq2);
      while ( !digitalRead(DOWN_BTN)) {} //debounce
      delay(100);
    }

    if ( !digitalRead(UP_BTN) )
    {
     step_index -=1;
     if (step_index < 0 ) 
    {
     step_index = 5;
    }
    disp_step(fq2);
      while ( !digitalRead(UP_BTN)) {} //debounce
      delay(100);
    }
}

void disp_step(long freq)
{
  int ofst = 0;
  ofst=step_index * (-1) + 8; // calculate offset for step indicator
  if (freq >= 10000000) ofst = ofst + 1;
  lcd.setCursor(0, 1);
  lcd.clearLine();
  lcd.setCursor(0, 1);
  ofst = ofst * 6;    // each ascii space on lcd is 6 lines wide
  lcd.setCursor(ofst, 1);
  lcd.print("^");         //Erase old caret, write a new caret
  lcd.setCursor(66,1);
  if (cw_offset > 0) lcd.print("USB");
  else lcd.print("LSB");
}

void setup(void) 
{
  Wire.begin();     //initialize wire functionality
  lcd.begin(84, 48);

  //read saved freq from eeprom. Reset value if it is uninitialized or unreasonable
  fq = eeprom_read_dword((const uint32_t *)EE_SAVED_FQ); 
  if (fq < 7000000 | fq > 7300000) {
    fq=7030000;
    eeprom_write_dword((uint32_t *)EE_SAVED_FQ, fq);
  }
  //read saved calibration offset from eeprom. Reset value if it is uninitialized or unreasonable.
  cal_ofst = eeprom_read_dword((const uint32_t *)EE_SAVED_CAL);  
  if (cal_ofst < -4096 | cal_ofst > 4096) {
    cal_ofst=0;
    eeprom_write_dword((uint32_t *)EE_SAVED_CAL, cal_ofst);
  }

  //eeprom_write_dword((uint32_t *)EE_SAVED_BFO, bfo);
   //read saved bfo calibration from eeprom. Reset value if it is uninitialized or unreasonable.
   if_freq = eeprom_read_dword((const uint32_t *)EE_SAVED_BFO);  
   if (if_freq < 4900000 | if_freq > 4920000) {
    if_freq = if_guess;
    eeprom_write_dword((uint32_t *)EE_SAVED_BFO, if_freq);
  }

    wpm = eeprom_read_dword((const uint32_t *)EE_KEYER_SPEED); //read saved keyer speed
    if (wpm < 5 | wpm > 35) {
      wpm = 13;                                                //set wpm to 13 if unreasonable
      eeprom_write_dword((uint32_t *)EE_KEYER_SPEED, wpm);
    }
  
    //setup input ports with internal pullup resistors enabled
    pinMode(ENCODER_A, INPUT_PULLUP);
    pinMode(ENCODER_B, INPUT_PULLUP);
    pinMode(ENCODER_BTN, INPUT_PULLUP);
    pinMode(DOWN_BTN, INPUT_PULLUP);
    pinMode(UP_BTN, INPUT_PULLUP);
    pinMode(ENTER_BTN, INPUT_PULLUP);
    pinMode(DIT_KEY, INPUT_PULLUP);
    pinMode(DAH_KEY, INPUT_PULLUP);
    //pinMode(BACKLIGHT, OUTPUT);

    pinMode(XMIT_PWR, OUTPUT);    //this output applies power to the finals for transmitting and shapes the CW wave
    pinMode(XMIT_EN, OUTPUT);     //gates CLK2 to finals
    digitalWrite(XMIT_PWR, 0);    //turn off power to finals
    digitalWrite(XMIT_EN, LOW);  //disable CLK2 drive to finals

    //digitalWrite(BACKLIGHT, LOW); //turn on backlight
 
  
    Si.init(25000000L);             //si5351 crystal freq 25MHz
    Si.correction(cal_ofst);        // correct si5351 crystal frequency - calculate for each new si5351 board

// Enable the desired outputs with some frequencies
    bfo = if_freq - cw_offset;      // calculate bfo freq
    Si.setFreq(1, bfo);             // CLK1 output bfo
    vfo=fq - if_freq;               // calculate vfo
    Si.setFreq(0, vfo);             // CLK0 output vfo

// set drive levels
    Si.setPower(0, SIOUT_4mA);
    Si.setPower(1, SIOUT_4mA);
    Si.setPower(2, SIOUT_8mA);

// enable the outputs
    Si.enable(0);
    Si.enable(1);
    Si.disable(2);                 //turn off xmit
    lcd.setCursor(18,1);            //set cursor to center text
    lcd.print("2N2-40++");
    delay(1000);

    keyerState = IDLE;
    keyerControl = IAMBICB;      // Or 0 for IAMBICA
    loadWPM(wpm);                 // set keyer speed
}

void update_PaddleLatch()
{
    if (digitalRead(DIT_KEY) == LOW) {
        keyerControl |= DIT_L;
    }
    if (digitalRead(DAH_KEY) == LOW) {
        keyerControl |= DAH_L;
    }
}

void loadWPM (int wpm)
{
    ditTime = 1200/wpm;
}

void check_menu(void)
{
  if (!digitalRead(ENCODER_BTN) ) {
    long menu_timer = millis();
    while (!digitalRead(ENCODER_BTN)) {}
    menu_timer = millis() - menu_timer;
    delay(100);
    if (menu_timer > 500) {       //encoder button pressed longer than 1/2 second
      lcd.clear();
      lcd.setCursor(0,0);         //set cursor to column 0, row 1
      lcd.print("Adj. Keyer spd");
      lcd.setCursor(0,1);
      lcd.print("with encoder");
      lcd.setCursor(0,2);
      lcd.clearLine();
      sprintf(LCDstr, "%2d", wpm);    //create string to print
      lcd.print(LCDstr);            //display wpm on line 3
      while (digitalRead(ENCODER_BTN)) {    //loop until encoder is pressed again
        char result = r.process();
        if (result) { //execute if encoder moved
          if (result == DIR_CW) {
            wpm +=1;
            if (wpm > 35) wpm = 35;
            lcd.setCursor(0,2);
            lcd.clearLine();
            sprintf(LCDstr, "%2d", wpm);    //create string to print
            lcd.print(LCDstr);            //display wpm on line 3
          }
          else if (result == DIR_CCW) {
            wpm -=1;
            if (wpm < 5) wpm = 5;
            lcd.setCursor(0,2);
            lcd.clearLine();
            sprintf(LCDstr, "%2d", wpm);    //create string to print
            lcd.print(LCDstr);            //display wpm on line 3
          }
        }
      }
      delay(100);     //encoder button pressed to exit menu. debounce
      lcd.clear();    // clear LCD and re-display frequency for operation
      disp_freq(fq); 
      disp_step(fq); 
      loadWPM(wpm);                 // set keyer speed
      //eeprom_write_dword((uint32_t *)EE_KEYER_SPEED, wpm); //save new speed in EEPROM
      EEPROM.update(EE_KEYER_SPEED, wpm); //save new speed in EEPROM
    }
    else {                          //press was less than 1/2 second
      //digitalWrite(BACKLIGHT, !digitalRead(BACKLIGHT)); //toggle backlight
      delay(100);
    }
  }
}

void check_sideband(void)
{
    if (!digitalRead(ENTER_BTN) ) {
    delay(100);
    while ( !digitalRead(ENTER_BTN) ) {}
    delay(100);
    cw_offset *= -1;  // flip sign of cw_offset
    disp_step(fq);    // display new sideband indicator
    bfo = if_freq - cw_offset;      // re-calculate bfo freq
    Si.setFreq(1, bfo);             // change bfo to new sideband
    }
}

void measure_volts(void)
{
  vbatt = 3 * analogRead(VOLTS) * vpb;
  lcd.setCursor(0,5);
  //lcd.clearLine();
  sprintf(LCDstr, "%d.%02dV", (int)vbatt, (int)(vbatt*100)%100);    //create string to print
  lcd.print(LCDstr);            //display battery voltage on line 6
}

void loop(void)                    //Main program loop
{
  if (!digitalRead(ENTER_BTN) ) {
    delay(100);
    while ( !digitalRead(ENTER_BTN) ) {}
    delay(100);
    calib();              //if enter button is pushed during startup, run calibration routine
  }

  static long ktimer;     // timer variable for keyer
  
  disp_freq(fq);          //display the startup frequency, 7,030.000 Hz
  disp_step(fq);          //display inital step indicator
  
  while (1){
      char result = r.process();
      if (result) { //execute if encoder moved
        if (result == DIR_CW) {
          set_frequency(1);
          disp_freq(fq);
        }
         else if (result == DIR_CCW) {
         set_frequency(-1);
         disp_freq(fq);
         }
      }
 
/*// transmit while key pressed                   //This code is locked out during receiver testing
      if ( !digitalRead(DIT_KEY) ) {
        tone(S_TONE,cw_offset);
        Si.disable(0); //turn off vfo
        Si.disable(1); //turn off bfo
        Si.setFreq(2, fq); //set transmit frequency
        Si.enable(2); //turn on xmit frequency
        digitalWrite(XMIT_PWR, 1); //turn on power to final amplifier
        while( !digitalRead(DIT_KEY)) {} //wait for unkey
        digitalWrite(XMIT_PWR, 0); //turn off power to final amplifier
        delay(20); //wait to turn off xmit to allow cw envelope to decay and avoid keyclicks

        noTone(S_TONE);
        Si.disable(2); //turn off xmit
        Si.setFreq(1, bfo); // recover bfo output
        Si.enable(0); //turn on vfo
        Si.enable(1); //turn on bfo
      } */
      
//keyer control section
switch (keyerState) {
    case IDLE:
        // Wait for direct or latched paddle press
        if ((digitalRead(DIT_KEY) == LOW) ||
                (digitalRead(DAH_KEY) == LOW) ||
                    (keyerControl & 0x03)) {
            update_PaddleLatch();
            keyerState = CHK_DIT;
        }
        break;
 
    case CHK_DIT:
        // See if the dit paddle was pressed
        if (keyerControl & DIT_L) {
            keyerControl |= DIT_PROC;
            ktimer = ditTime;
            keyerState = KEYED_PREP;
        }
        else {
            keyerState = CHK_DAH;
        }
        break;
 
    case CHK_DAH:
        // See if dah paddle was pressed
        if (keyerControl & DAH_L) {
            ktimer = ditTime*3;
            keyerState = KEYED_PREP;
        }
        else {
            keyerState = IDLE;
        }
        break;
 
    case KEYED_PREP:
        // Assert key down, start timing, state shared for dit or dah
        tone( S_TONE, abs(cw_offset) );
        Si.disable(0); //turn off vfo
        Si.disable(1); //turn off bfo
        Si.setFreq(2, fq); //set transmit frequency
        Si.enable(2); //turn on xmit frequency
        digitalWrite(XMIT_EN, HIGH);  //enable CLK2 drive to finals
        digitalWrite(XMIT_PWR, HIGH); //turn on power to final amplifier and arduino L LED
        ktimer += millis();                 // set ktimer to interval end time
        keyerControl &= ~(DIT_L + DAH_L);   // clear both paddle latch bits
        keyerState = KEYED;                 // next state
        break;
 
    case KEYED:
        // Wait for timer to expire
        if (millis() > ktimer) {            // are we at end of key down ?
            digitalWrite(XMIT_PWR, LOW); //turn off power to final amplifier and LED
            delay(20); //wait to turn off xmit to allow cw envelope to decay and avoid keyclicks
            noTone(S_TONE);  //turn off sidetone
            digitalWrite(XMIT_EN, LOW);  //disable CLK2 drive to finals
            Si.disable(2); //turn off xmit
            Si.setFreq(1, bfo); // recover bfo output
            Si.enable(0); //turn on vfo
            Si.enable(1); //turn on bfo
            ktimer = millis() + ditTime;    // inter-element time
            keyerState = INTER_ELEMENT;     // next state
        }
        else if (keyerControl & IAMBICB) {
            update_PaddleLatch();           // early paddle latch in Iambic B mode
        }
        break;
 
    case INTER_ELEMENT:
        // Insert time between dits/dahs
        update_PaddleLatch();               // latch paddle state
        if (millis() > ktimer) {            // are we at end of inter-space ?
            if (keyerControl & DIT_PROC) {             // was it a dit or dah ?
                keyerControl &= ~(DIT_L + DIT_PROC);   // clear two bits
                keyerState = CHK_DAH;                  // dit done, check for dah
            }
            else {
                keyerControl &= ~(DAH_L);              // clear dah latch
                keyerState = IDLE;                     // go idle
            }
        }
        break;
    }

    check_step_change(fq);

    check_menu();

    check_sideband();

    measure_volts();
      
  }

}
